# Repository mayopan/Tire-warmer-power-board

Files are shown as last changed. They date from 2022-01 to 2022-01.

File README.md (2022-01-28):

# Tire-warmer-power-board

  This is the software for seeeduino xiao on the original replacement power board of G-FORCE TYRE WARMER.
  http://www.gforce-hobby.jp/products/G0033.html
  
  Xiao senses temparature of 4 tires with ADS1115.
  Xiao controls 4 heater output for each tire with PWM PID.
  User interface is the same as the G-FORCE one, but the interface board is new.
  mcp23017 on it controls 1602 LCD and 4 button inputs through I2C connection with xiao.
  It's like Adafruit LCD keypad board.
  https://learn.adafruit.com/adafruit-16x2-character-lcd-plus-keypad-for-raspberry-pi
  
  If you want to know schematic, PCB layout, LTSpice sim, refer to github site below.
  https://github.com/mayopan/Tire-warmer-power-board.git

  Date:       January 29, 2022
  Copyright:  mayopan = ROUTE 246 GARAGE
  License:    MIT. See license file for more information but you can basically do whatever you want with this code.

  Dependancy: It uses 2 library for ADC and LCD. LCD library is wrapped in the TireWarmer library.
    * https://github.com/wollewald/ADS1115_WE.git
    * lincomatic/LiquidTWI2 @ ^1.2.7

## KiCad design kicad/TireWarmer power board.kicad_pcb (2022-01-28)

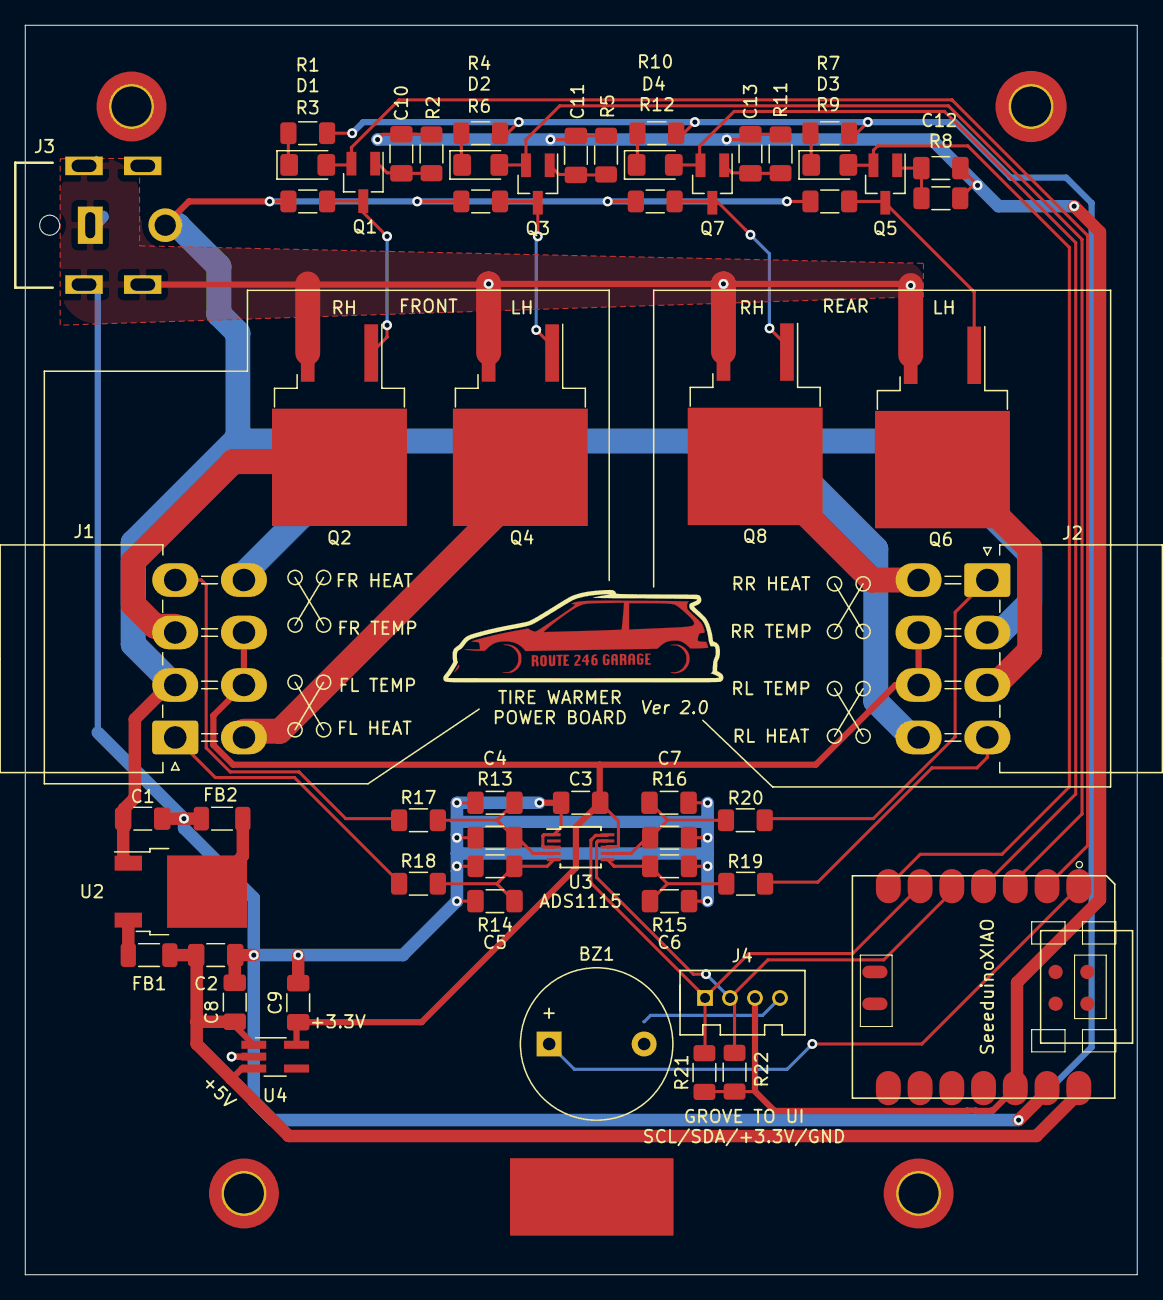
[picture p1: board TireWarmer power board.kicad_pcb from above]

Board: 2 copper layers, 89.0 x 100.0 mm, 58 parts (0 on the bottom side), 38 nets.

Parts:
BZ1: Buzzer; Buzzer_12x9.5RM7.6
C1, C4, C5, C6, C7: 100n; C_1206_3216Metric_Pad1.33x1.80mm_HandSolder
C2, C3, C8, C9, C10, C11, C12, C13: 1u; C_1206_3216Metric_Pad1.33x1.80mm_HandSolder
D1, D2, D3, D4: LED; LED_1206_3216Metric_Pad1.42x1.75mm_HandSolder
FB1, FB2: 1.5k; L_1206_3216Metric_Pad1.22x1.90mm_HandSolder
J1, J2: Morex mini-fit jr 5569-08A2; Molex_Mini-Fit_Jr_5569-08A2_2x04_P4.20mm_Horizontal
J3: Jack-DC; CUI_PJ-082BH
J4: GROVE-CONNECTOR-DIP_4P-2.0_; HW4-2.0
Q1, Q3, Q5, Q7: BSS138; SOT-23_Handsoldering
Q2, Q4, Q6, Q8: IRF3205; TO-263-2
R1, R4, R7, R10: 150; R_1206_3216Metric_Pad1.30x1.75mm_HandSolder
R2, R5, R8, R11: 10k; R_1206_3216Metric_Pad1.30x1.75mm_HandSolder
R3, R6, R9, R12, R21, R22: 1k; R_1206_3216Metric_Pad1.30x1.75mm_HandSolder
R13, R14, R15, R16: 12k; R_1206_3216Metric_Pad1.30x1.75mm_HandSolder
R17, R18, R19, R20: 7.5k; R_1206_3216Metric_Pad1.30x1.75mm_HandSolder
U1: SeeeduinoXIAO; Seeeduino XIAO-MOUDLE14P-2.54-21X17.8MM
U2: LM78M05; TO-252-2
U3: ADS1115IDGS; TSSOP-10_3x3mm_P0.5mm
U4: ADP151TUJZ3.3-EPR2; TSOT-23-5_HandSoldering

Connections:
+3.3VA: C3.1, C9.1, J1.6, J1.7, J2.6, J2.7, U3.8, U4.5
+3V3: C10.1, C11.1, C12.1, C13.1, J4.3, R2.1, R5.1, R8.1, R11.1, R21.1, R22.1, U1.12
+5V: C2.1, C8.1, FB1.1, U1.14, U4.1, U4.3
+12V: C1.1, J1.2, J1.8, J2.2, J2.8, J3.1, R3.1, R6.2, R9.1, R12.1, U2.1
GND: BZ1.2, C1.2, C2.2, C3.2, C4.2, C5.2, C6.2, C7.2, C8.2, C9.2, FB2.2, J3.2, J4.4, Q2.3, Q4.3, Q6.3, Q8.3, R1.2, R4.2, R7.2, R10.2, R13.2, R14.2, R15.2, R16.2, U1.13, U3.1, U3.3, U4.2
unnamed: BZ1.1, U1.1
unnamed: C4.1, R13.1, R17.2, U3.4
unnamed: C5.1, R14.1, R18.2, U3.5
unnamed: C6.1, R15.1, R19.2, U3.6
unnamed: C7.1, R16.1, R20.2, U3.7
unnamed: C10.2, Q1.1, R2.2
unnamed: C11.2, Q3.1, R5.2
unnamed: C12.2, Q5.1, R8.2
unnamed: C13.2, Q7.1, R11.2
unnamed: D1.1, R1.1
unnamed: D1.2, Q1.2, U1.2
unnamed: D2.1, R4.1
unnamed: D2.2, Q3.2, U1.3
unnamed: D3.1, R7.1
unnamed: D3.2, Q5.2, U1.7
unnamed: D4.1, R10.1
unnamed: D4.2, Q7.2, U1.4
unnamed: FB1.2, U2.3
unnamed: FB2.1, U2.2
unnamed: J1.1, R18.1
unnamed: J1.3, Q2.2
unnamed: J1.4, R17.1
unnamed: J1.5, Q4.2
unnamed: J2.1, R20.1
unnamed: J2.3, Q6.2
unnamed: J2.4, R19.1
unnamed: J2.5, Q8.2
unnamed: J4.1, R21.2, U1.6, U3.10
unnamed: J4.2, R22.2, U1.5, U3.9
unnamed: Q1.3, Q2.1, R3.2
unnamed: Q3.3, Q4.1, R6.1
unnamed: Q5.3, Q6.1, R9.2
unnamed: Q7.3, Q8.1, R12.2

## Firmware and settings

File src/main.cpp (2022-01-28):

/*
  This is the software for seeeduino xiao on the original replacement power board of G-FORCE TYRE WARMER.
  http://www.gforce-hobby.jp/products/G0033.html
  Xiao senses temparature of 4 tires with ADS1115.
  Xiao controls 4 heater output for each tire with PWM PID.
  User interface is the same as the G-FORCE one, but the interface board is new.
  mcp23017 on it controls 1602 LCD and 4 button inputs through I2C connection with xiao.
  It's like Adafruit LCD keypad board.
  https://learn.adafruit.com/adafruit-16x2-character-lcd-plus-keypad-for-raspberry-pi
  
  If you want to know schematic, PCB layout, LTSpice sim, refer to github site below.
  https://github.com/mayopan/Tire-warmer-power-board.git

  Date:       January 29, 2022
  Copyright:  mayopan = ROUTE 246 GARAGE
  License:    MIT. See license file for more information but you can basically do whatever you want with this code.

  Dependancy: It uses 2 library for ADC and LCD. LCD library is wrapped in the TireWarmer library.
    * https://github.com/wollewald/ADS1115_WE.git
    * lincomatic/LiquidTWI2 @ ^1.2.7
  

*/

#include <Arduino.h>
#include <TireWarmer.h>
#include<ADS1115_WE.h> 
#include<Wire.h>
#define I2C_ADDRESS 0x48

ADS1115_WE adc = ADS1115_WE(I2C_ADDRESS);

float readChannel(ADS1115_MUX channel) {
  float voltage = 0.0;
  adc.setCompareChannels(channel);
  voltage = adc.getResult_V();
  return voltage;
}

WarmerDisp warmer(0x20, 1);

const uint16_t framerate = 5;//LCDのフレームレート Hz
uint16_t lastsecond = 0;
uint16_t lastframe = 0;
uint16_t sps = 0;

float P, I, D;
float dP, dI, dD, predP;
const float Kp = 8;    //5.5
const float Ki = 0.2;  //0.3
const float Kd = 0.08; //0.1

const byte HEATER_FR_PIN = PIN_A1; //Heater control output
const byte HEATER_FL_PIN = PIN_A2;
const byte HEATER_RR_PIN = PIN_A3;
const byte HEATER_RL_PIN = PIN_A6;
const byte SOUND_PIN = PIN_A0;



void setup()
{
  Serial.begin(115200);
  warmer.init(HEATER_FR_PIN, HEATER_FL_PIN, HEATER_RR_PIN, HEATER_RL_PIN, SOUND_PIN);

  warmer.setCursor(0, 1);
  if(!adc.init()){
    Serial.println("ADS1115 not connected!");
    warmer.print("NO ADC!");
  }
  else
  {
    Serial.println("ADS1115 found!");
    adc.setVoltageRange_mV(ADS1115_RANGE_2048); //comment line/change parameter to change range
    adc.setCompareChannels(ADS1115_COMP_0_GND); //comment line/change parameter to change channel
    adc.setConvRate(ADS1115_128_SPS);
    adc.setMeasureMode(ADS1115_CONTINUOUS);
    warmer.print("ADC OK!");
  }
  delay(500);
  warmer.clear();
  warmer.disp_setmode();
}

void loop()
{
  char valuetext[10];
  uint16_t frame = millis() / (1000/framerate);
  uint16_t second = warmer.countdown_target - (uint16_t)(millis() / 1000);

//タイマーが0になったらヒーターを止めて終了モードへ
  if (second == 0)
  {
    warmer.stop_heater();
    warmer.disp_finishmode();
  }

//ヒートモード中にセレクトボタンが押されたらヒーターを止めて設定モードへ
  else if (warmer.readButtons() == SELECT ||warmer.readButtons() == RIGHT)
  {
    warmer.stop_heater();
    warmer.mode = SET_FR_TEMP;
    sound(SOUND_PIN,100,2);
    warmer.disp_setmode();
  }

//ヒートモード　ターゲット温度にPID制御
  else if (warmer.mode == HEAT_MODE)
  {
    uint8_t min = second / 60;
    second = second % 60;

    for (int i = warmer.HEATER_FR; i <= warmer.HEATER_RL; i++)
    {
      ADS1115_MUX channel;
      switch (i)
      {
      case warmer.HEATER_FR:
        channel = ADS1115_COMP_0_GND;
        break;
      case warmer.HEATER_FL:
        channel = ADS1115_COMP_1_GND;
        break;
      case warmer.HEATER_RL:
        channel = ADS1115_COMP_2_GND;
        break;
      case warmer.HEATER_RR:
        channel = ADS1115_COMP_3_GND;
        break;      
      default:
        break;
      }
      float voltage=readChannel(channel);
      if(voltage==0)
      {
        warmer.stop_heater();
        Serial.println("No thermistor data");
        warmer.disp_errormode();
      }

      warmer.temp[i] = voltage_to_temp(voltage);
      if (warmer.temp[i] < 0)
        warmer.temp[i] = 0;

      //速度型PID制御
      float dt = 1.0 / warmer.sample_rate;
      if (i <= warmer.HEATER_FL)
      {
        warmer.dtemp[i] = ((float)warmer.target[0] - warmer.temp[i]) / dt; //偏差の微分 FR
      }
      else
      {
        warmer.dtemp[i] = ((float)warmer.target[1] - warmer.temp[i]) / dt; //偏差の微分 RR
      }
      P = warmer.dtemp[i] - warmer.pdtemp[i];
      warmer.pdtemp[i] = warmer.dtemp[i];
      I = warmer.dtemp[i] * dt;
      D = (P - warmer.preP[i]) / dt;
      warmer.preP[i] = P;

      warmer.duty[i] += (Kp * P + Ki * I + Kd * D) * dt;

      //dutyを0-255にクリップ
      if (warmer.duty[i] < 0 || warmer.temp[i]==0)
        warmer.duty[i] = 0;
      else if(warmer.duty[i]>255)
        warmer.duty[i]=255;
      uint32_t duty_out=(uint32_t)warmer.duty[i];

      analogWrite(warmer.heater_pin[i], duty_out);

      //シリアルでの監視用
      if (i <= warmer.HEATER_FL)
        Serial.print("F");
      else
        Serial.print("R");
      if (i % 2 == 0)
        Serial.print("R: ");
      else
        Serial.print("L:  ");
      //Serial.print(voltage,5);
      dtostrf(warmer.temp[i], 5, 2, valuetext);
      Serial.printf("%sC ", valuetext);

      Serial.printf("duty%3lu%% ",(uint32_t)(duty_out/2.55));
      dtostrf(warmer.duty[i], 5, 1, valuetext);
      Serial.printf("%s  ", valuetext);
    }
    Serial.printf("%2dfps\n", warmer.sample_rate);

    //PID計算用のADCサンプルレート取得
    if (second != lastsecond)
    {
      lastsecond = second;
      warmer.sample_rate = sps;
      sps = 0;
    }
    else
    {
      sps++;
    }

    //frameカウントが変わった時だけlcd更新
    if (frame != lastframe)
    {
      warmer.disp_heatmode(min, (uint8_t)second);
      lastframe = frame;
    }
  }
  else
  {
    warmer.stop_heater();
    Serial.println("Some error!");
    warmer.disp_errormode();
  }
}
